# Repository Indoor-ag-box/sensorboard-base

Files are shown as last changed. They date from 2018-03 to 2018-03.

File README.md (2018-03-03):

[Indoor Agriculture Project](https://docs.google.com/document/d/1ArcZqPgIa82AwvjWtvZ9FeCffs26SfxBspnVomPGeAw/edit#)

## Sensorboard

The Sensorboard is based off of the [Arduino Nano](https://store.arduino.cc/usa/arduino-nano). It has a very minimal UI to:

* Enable and disable sensors on the board

* Select the ID number for the board

* Display current sensor readings

* Calibrate sensors (Calibration factors are stored in EEPROM)

The UI is based on an:

* [8x2 Char LCD Module](https://www.digikey.com/product-detail/en/newhaven-display-intl/NHD-0208BZ-FL-YBW/NHD-0208BZ-FL-YBW-ND/1701135)

* 3 Pushbuttons

The sensorboard reports all RAW values back to the pi. These may be filtered and averaged etc, but conversion from VOLTAGE to the actual data is handled by the pi.

The connections are as follows:

### Arduino Pins

<table>
  <tr>
    <td>Pin Name</td>
    <td>Pin Function</td>
    <td>Short Name</td>
    <td>Location</td>
  </tr>
  <tr>
    <td>D2 (INT)</td>
    <td>Misc Digital Input</td>
    <td>EMDI0</td>
    <td>Screw Terminal</td>
  </tr>
  <tr>
    <td>D3
</td>
    <td>Shift Register Serial</td>
    <td>SREG_SER</td>
    <td>On Board
</td>
  </tr>
  <tr>
    <td>D4</td>
    <td>Shift Register SRCLK</td>
    <td>SREG_SRCLK</td>
    <td>On Board</td>
  </tr>
  <tr>
    <td>D5</td>
    <td>CO2 Sensor UART TX</td>
    <td>ECO2R</td>
    <td>Board Connector</td>
  </tr>
  <tr>
    <td>D6</td>
    <td>CO2 Sensor UART RX</td>
    <td>ECO2R</td>
    <td>Board Connector</td>
  </tr>
  <tr>
    <td>D7 (SDA)</td>
    <td>RGB Color Sensor I2C SDA</td>
    <td>ECSDA</td>
    <td>Board Connector</td>
  </tr>
  <tr>
    <td>D8 (SCL)</td>
    <td>RGB Color Sensor I2C SCL</td>
    <td>ECSCL</td>
    <td>Board Connector</td>
  </tr>
  <tr>
    <td>D9</td>
    <td>Load Sensor Data</td>
    <td>LSDAT</td>
    <td>On Board</td>
  </tr>
  <tr>
    <td>D10</td>
    <td>Load Sensor Clock</td>
    <td>LSCLK</td>
    <td>On Board</td>
  </tr>
  <tr>
    <td>D11 (PWM)</td>
    <td>LCD Backlight LED+</td>
    <td>OLED+</td>
    <td>On Board</td>
  </tr>
  <tr>
    <td>D12</td>
    <td>Shift Register RCLK</td>
    <td>SREG_RCLK</td>
    <td>On Board</td>
  </tr>
  <tr>
    <td>D13</td>
    <td>Voltage Divider Enable</td>
    <td>DIVEN</td>
    <td>On Board</td>
  </tr>
  <tr>
    <td>A0</td>
    <td>Mux Sig Pin</td>
    <td>MUX_SIG</td>
    <td>On Board</td>
  </tr>
  <tr>
    <td>A1</td>
    <td>Mux S0</td>
    <td>MUX_S0</td>
    <td>On Board</td>
  </tr>
  <tr>
    <td>A2</td>
    <td>Mux S1</td>
    <td>MUX_S1</td>
    <td>On Board</td>
  </tr>
  <tr>
    <td>A3</td>
    <td>Mux S2</td>
    <td>MUX_S2</td>
    <td>On Board</td>
  </tr>
  <tr>
    <td>A4</td>
    <td>Hardware I2C SDA (For External Comms)</td>
    <td>I2C_SDA</td>
    <td>Board Connector</td>
  </tr>
  <tr>
    <td>A5</td>
    <td>Hardware I2C SCL (For External Comms)</td>
    <td>I2C_SDL</td>
    <td>Board Connector</td>
  </tr>
  <tr>
    <td>A6</td>
    <td>Mux S3</td>
    <td>MUX_S3</td>
    <td>On Board</td>
  </tr>
  <tr>
    <td>A7</td>
    <td>Mux EN</td>
    <td>MUX_EN</td>
    <td>On Board</td>
  </tr>
</table>

### Multiplexer

<table>
  <tr>
    <td>Pin Name</td>
    <td>Pin Function</td>
    <td>Short Name</td>
    <td>Location</td>
  </tr>
  <tr>
    <td>I0</td>
    <td>External Temp Sensor 0</td>
    <td>ETMP0</td>
    <td>Screw Terminal</td>
  </tr>
  <tr>
    <td>I1</td>
    <td>External Temp Sensor 1</td>
    <td>ETMP1</td>
    <td>Screw Terminal</td>
  </tr>
  <tr>
    <td>I2</td>
    <td>External Temp Sensor 2</td>
    <td>ETMP2</td>
    <td>Screw Terminal</td>
  </tr>
  <tr>
    <td>I3</td>
    <td>Soil Moisture Sensor 1 </td>
    <td>ESMT0</td>
    <td>Screw Terminal</td>
  </tr>
  <tr>
    <td>I4</td>
    <td>Soil Moisture Sensor 2</td>
    <td>ESMT0</td>
    <td>Screw Terminal</td>
  </tr>
  <tr>
    <td>I5</td>
    <td>Onboard Temp Sensor 0</td>
    <td>OTMP0</td>
    <td>On Board</td>
  </tr>
  <tr>
    <td>I6</td>
    <td>Onboard LDR 0</td>
    <td>OLDR0</td>
    <td>Board Connector</td>
  </tr>
  <tr>
    <td>I7</td>
    <td>O2 Sensor</td>
    <td>BO2G0</td>
    <td>On Board</td>
  </tr>
  <tr>
    <td>I8</td>
    <td>Ambient Humidity</td>
    <td>OMST0</td>
    <td>On board</td>
  </tr>
  <tr>
    <td>I9</td>
    <td>External Turbidity 0</td>
    <td>ETRB0</td>
    <td>Board Connector</td>
  </tr>
  <tr>
    <td>I10</td>
    <td></td>
    <td></td>
    <td></td>
  </tr>
  <tr>
    <td>I11</td>
    <td></td>
    <td></td>
    <td></td>
  </tr>
  <tr>
    <td>I12</td>
    <td>External Board Detection</td>
    <td>EEBD0</td>
    <td>Board Connector</td>
  </tr>
  <tr>
    <td>I13</td>
    <td>UI Button 1 (<)</td>
    <td>OUI0</td>
    <td>On Board</td>
  </tr>
  <tr>
    <td>I14</td>
    <td>UI Button 2 (*)</td>
    <td>OUI1</td>
    <td>On Board</td>
  </tr>
  <tr>
    <td>I15</td>
    <td>UI Button 3 (>)</td>
    <td>OUI2</td>
    <td>On Board</td>
  </tr>
</table>

A sensor board that we can stick all over the cabinet to sense critical environmental data. There will be more than one of these boards through the whole design. Sensor boards are based around the arduino mini which communicates with the Raspberry Pi as a master and the arduino responds as a [slave](https://www.arduino.cc/en/Tutorial/MasterWriter). 

Should be able to detect following variables (sensors are linked as hyperlinks):

* [Onboard temperature](https://www.digikey.com/product-detail/en/ametherm/1DC103K-EC/570-1229-ND/5970118)

* [External temperature (optional through some kind of screw terminal)](https://www.adafruit.com/product/372)

* [Ambient light Level](https://www.digikey.com/products/en?dc=16426)

* [Light Color](https://www.adafruit.com/product/1334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)

* [Ambient Moisture](https://www.digikey.com/product-detail/en/honeywell-sensing-and-productivity-solutions/HIH-4030-003/480-3167-ND/1886072)

* [Soil Moisture (external)](https://www.sparkfun.com/products/13322)

* [O2 Content](https://www.seeedstudio.com/Grove-Oxygen-Sensor%28ME2-O2-%D0%A420%29-p-1541.html)

* [CO2 Content](https://www.ebay.com/itm/New-MH-Z19B-Infrared-Carbon-Dioxide-CO2-Monitor-Sensor-Module-UART-PWM-Output/302501791946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)

* [Reservoir Water Turgidity](https://www.dfrobot.com/product-1394.html)

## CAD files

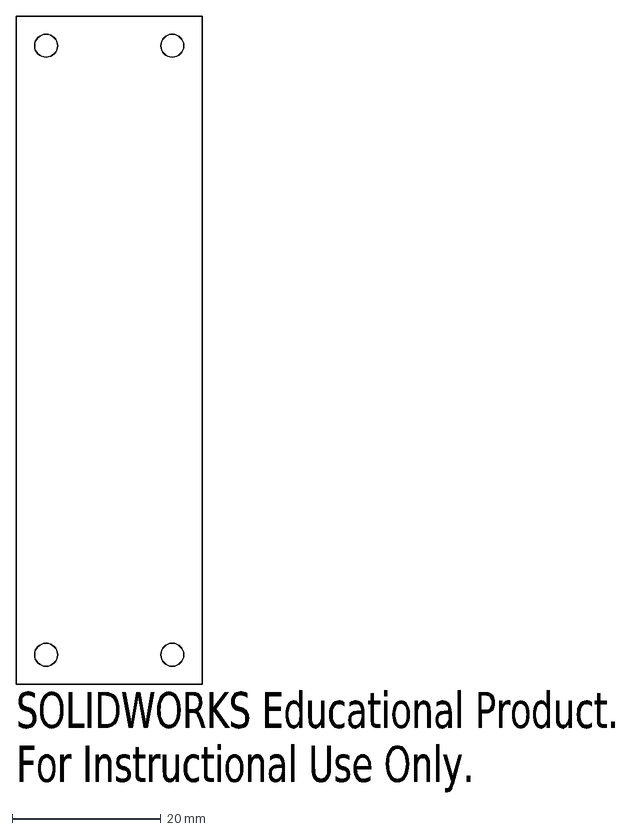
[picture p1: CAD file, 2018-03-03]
sensorboard_pcb.DXF
SOLIDWORKS Educational Product.
For Instructional Use Only.

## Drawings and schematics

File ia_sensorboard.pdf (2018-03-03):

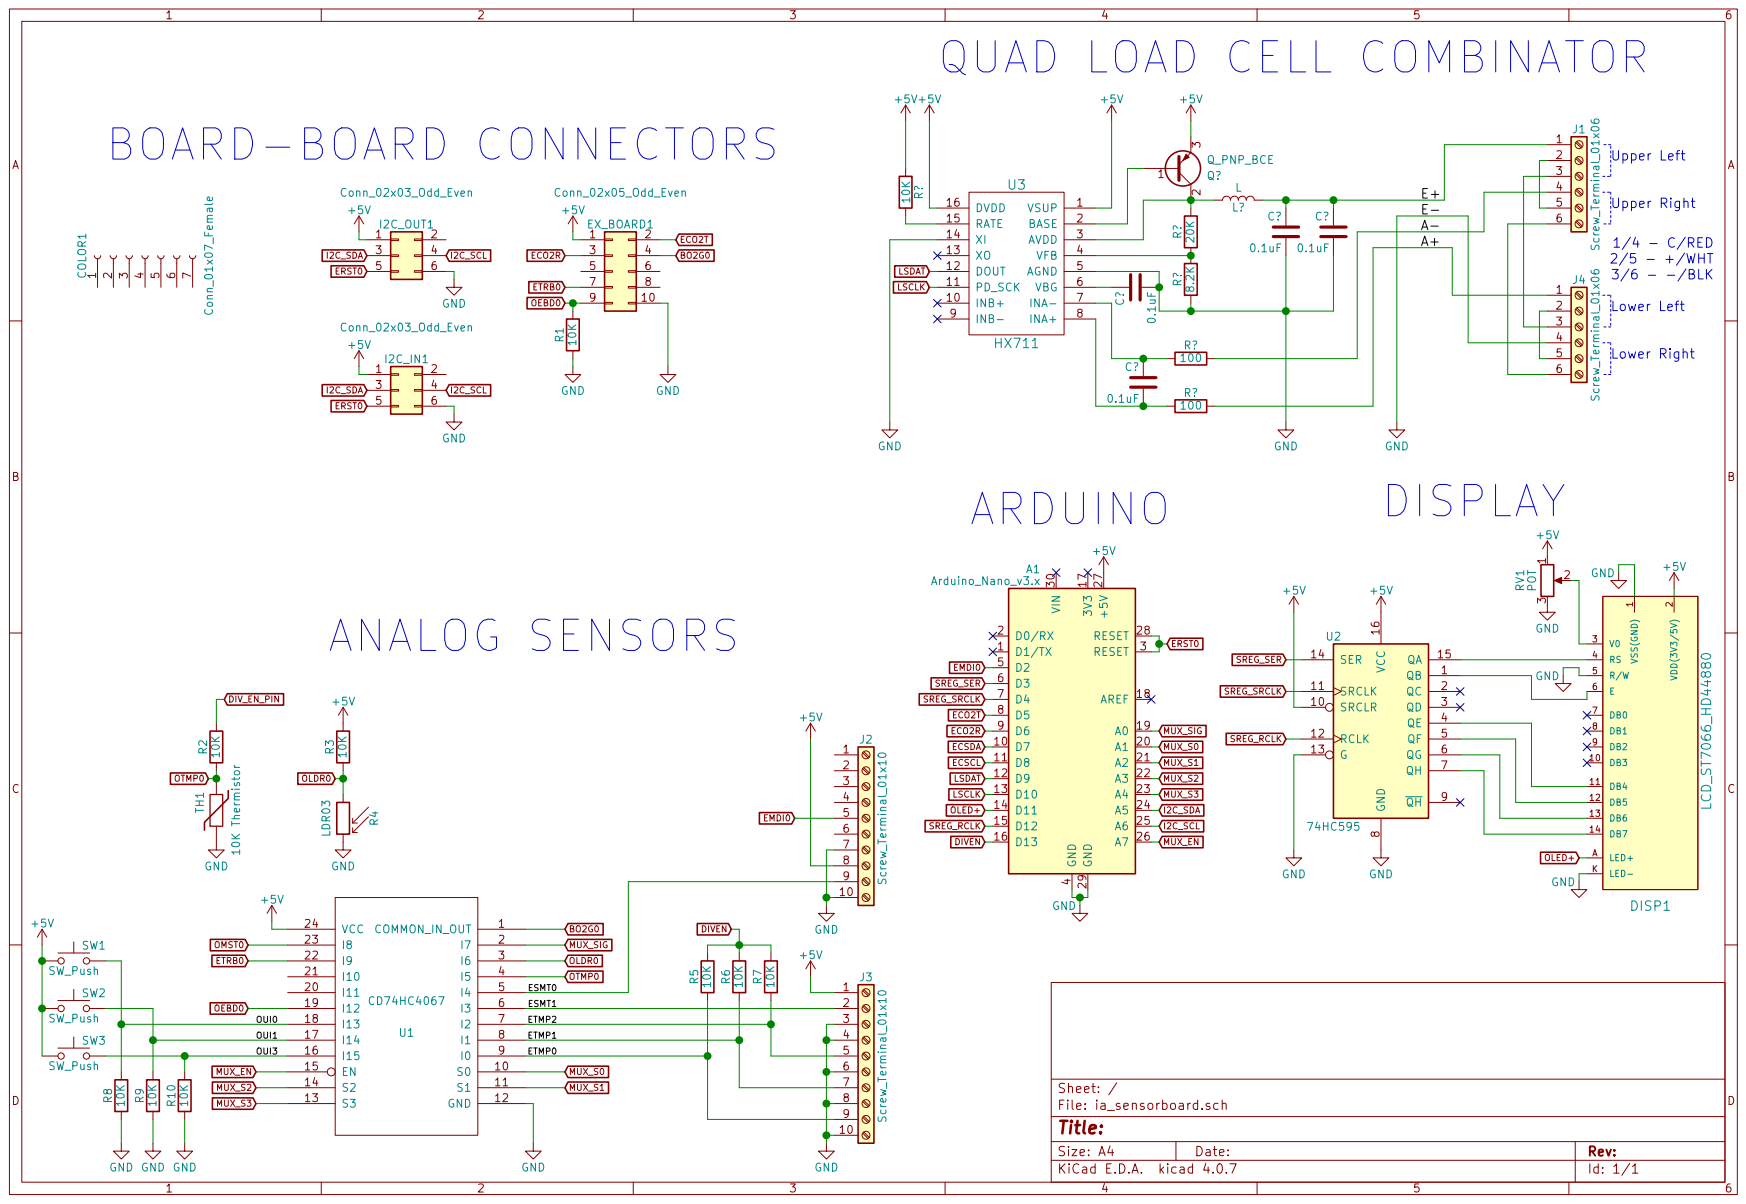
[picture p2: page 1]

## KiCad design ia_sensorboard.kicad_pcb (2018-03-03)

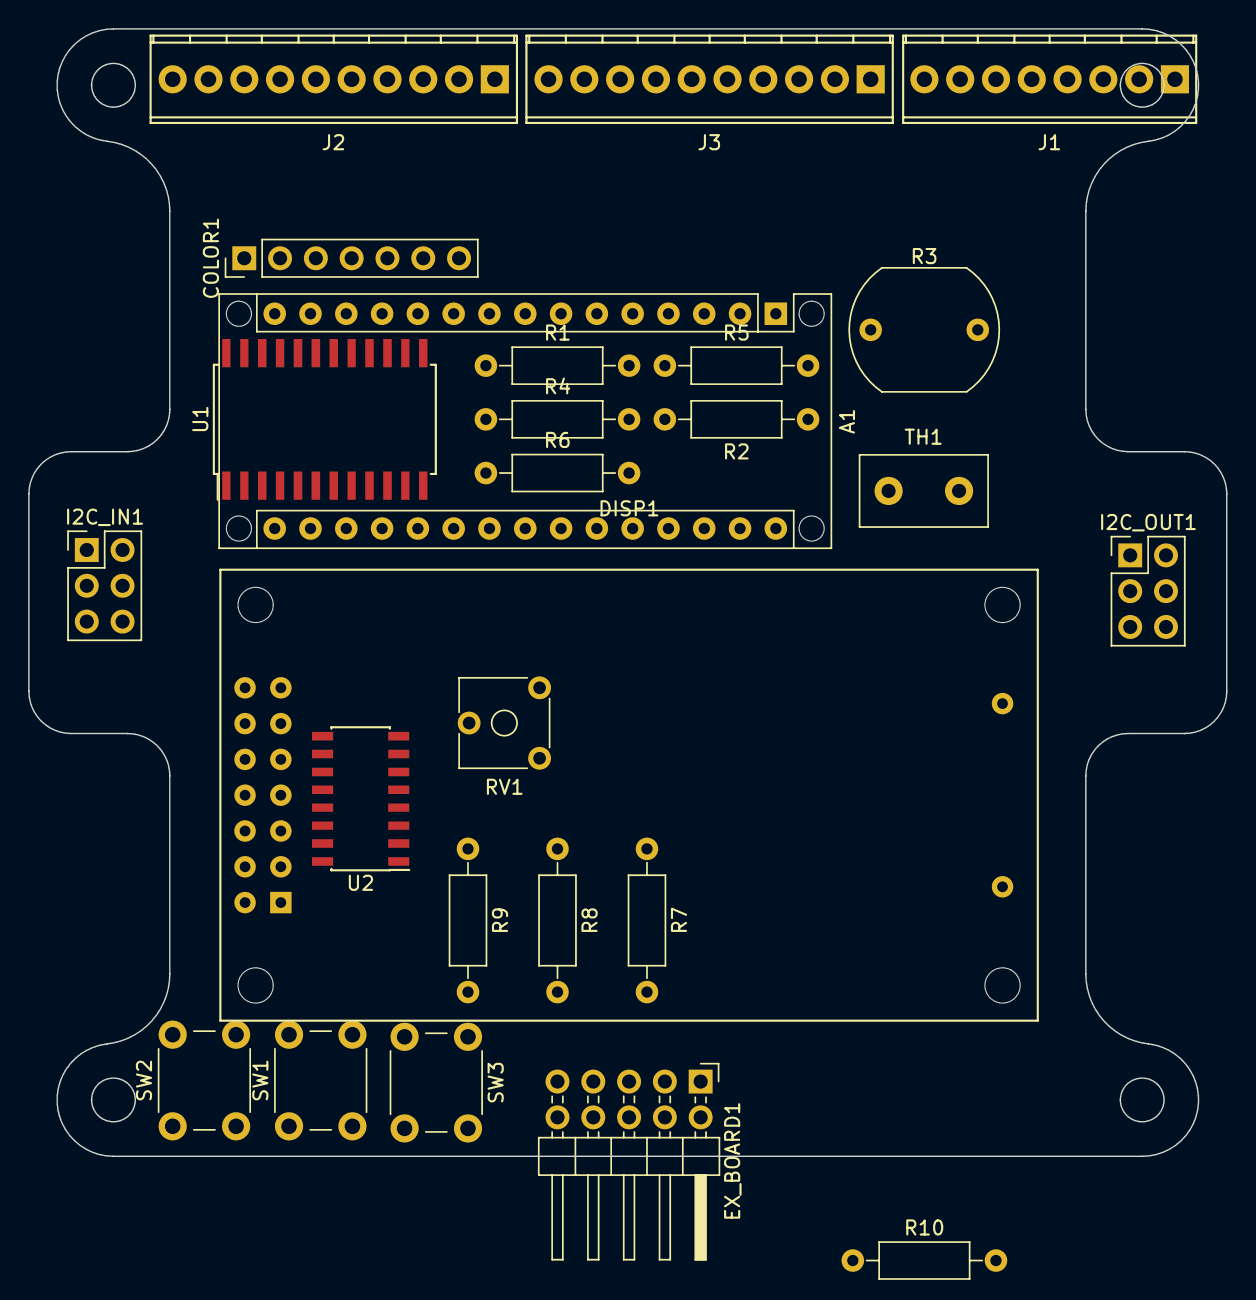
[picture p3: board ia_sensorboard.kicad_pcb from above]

Board: 2 copper layers, 85.0 x 80.0 mm, 26 parts (0 on the bottom side), 36 nets, no tracks yet.

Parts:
A1: Arduino_Nano_v3.x; Arduino_Nano_WithMountingHoles
COLOR1: Conn_01x07_Female; Pin_Header_Straight_1x07_Pitch2.54mm
DISP1: LCD_ST7066_HD44880; NHD-0208BZ-RN-YBW-33V
EX_BOARD1: Conn_02x05_Odd_Even; Pin_Header_Angled_2x05_Pitch2.54mm
I2C_IN1, I2C_OUT1: Conn_02x03_Odd_Even; Pin_Header_Straight_2x03_Pitch2.54mm
J1: Screw_Terminal_01x08; TerminalBlock_Phoenix_MPT-2.54mm_8pol
J2, J3: Screw_Terminal_01x10; TerminalBlock_Phoenix_MPT-2.54mm_10pol
R1, R2, R5, R6, R7, R8, R9, R10: 10K; R_Axial_DIN0207_L6.3mm_D2.5mm_P10.16mm_Horizontal
R3: 10K; Resistor_LDR_10x8.5_RM7.6
R4: LDR03; R_Axial_DIN0207_L6.3mm_D2.5mm_P10.16mm_Horizontal
RV1: POT; Potentiometer_Trimmer_ACP_CA6v_Horizontal
SW1, SW2, SW3: SW_Push; SW_PUSH_6mm
TH1: 10K Thermistor; C_Disc_D9.0mm_W5.0mm_P5.00mm
U1: CD74HC4067; SOIC-24W_7.5x15.4mm_Pitch1.27mm
U2: 74HC595; SOIC-16_3.9x9.9mm_Pitch1.27mm

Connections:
+5V: A1.27, DISP1.2, EX_BOARD1.1, I2C_IN1.1, I2C_OUT1.1, J2.8, J3.1, R3.2, RV1.1, SW1.1, SW2.1, SW3.1, U1.24, U2.16
/ESMT0: J2.9, U1.5
/ESMT1: J3.2, U1.6
/ETMP0: J3.9, R5.1, U1.9
/ETMP1: J3.7, R6.1, U1.8
/ETMP2: J3.5, R7.1, U1.7
/OUI0: R8.2, SW1.2, U1.18
/OUI1: R9.2, SW2.2, U1.17
/OUI3: R10.2, SW3.2, U1.16
BO2G0: EX_BOARD1.4, U1.1
DIV_EN_PIN: A1.16, R2.2, R5.2, R6.2, R7.2
ECO2R: A1.9, EX_BOARD1.3
ECO2T: A1.8, EX_BOARD1.2
EMDI0: A1.5, J2.5
EMDI1: A1.6, J2.6
ERST0: A1.28, I2C_IN1.5, I2C_OUT1.5
ETRB0: EX_BOARD1.7, U1.22
GND: DISP1.1, DISP1.5, EX_BOARD1.10, I2C_IN1.6, I2C_OUT1.6, J2.7, J2.10, J3.3, J3.4, J3.6, J3.8, J3.10, R1.1, R4.2, R8.1, R9.1, R10.1, RV1.3, TH1.2, U1.12, U2.8
I2C_SCL: A1.25, I2C_IN1.4, I2C_OUT1.4
I2C_SDA: A1.24, I2C_IN1.3, I2C_OUT1.3
MUX_EN: A1.26, U1.15
MUX_S0: A1.20, U1.10
MUX_S1: A1.21, U1.11
MUX_S2: A1.22, U1.14
MUX_S3: A1.23, U1.13
MUX_SIG: A1.19, U1.2
unnamed: DISP1.3, RV1.2
unnamed: DISP1.4, U2.15
unnamed: DISP1.6, U2.1
unnamed: DISP1.11, U2.4
unnamed: DISP1.12, U2.5
unnamed: DISP1.13, U2.6
unnamed: DISP1.14, U2.7
OEBD0: EX_BOARD1.9, R1.2, U1.19
OLDR0: R3.1, R4.1, U1.3
OTMP0: R2.1, TH1.1, U1.4
